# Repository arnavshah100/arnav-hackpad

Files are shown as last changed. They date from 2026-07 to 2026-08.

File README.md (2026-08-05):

# arnav-hackpad
<b>The arnav-hackpad is a mini-keyboard (or macropad) designed to act as an external number pad with some other cool capabilities, too!</b>

## Inspiration
In my essential technology class at school, two of my favorite modules were coding and 3D printing. When I joined the [Stardance summer program](https://stardance.hackclub.com/) and started looking at the recommended projects, I saw <b>hackpad</b>, and saw it as a great way to combine my love for those two subjects.
## Features
- 2 EC11 Rotary Encoders with Switches
- 10 MX-Style Key Switches
- 3-Part Case
## CAD Model
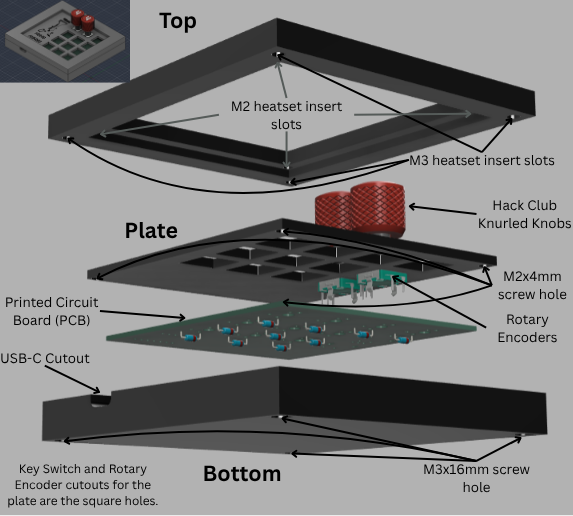
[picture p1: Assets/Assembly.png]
View Assembly on Autodesk Fusion's web version (https://a360.co/4eWbKiA)
\
This is my assembled macropad. Click on it to interact with the assembled macropad in Autodesk Fusion's web version.

There are 3 parts to the case: the top, the bottom, and the plate. The arnav-hackpad is top-mounted, meaning that the plate is attached to the top part. The design gives an ≈0.3mm printing tolerance. I added a cool design with my name on the plate, which you can see in the plate demo below!

[Click here to interact with the Plate.](https://a360.co/4g3hhWc)\
[Click here to interact with the Top part.](https://a360.co/4vbjJyh)\
[Click here to interact with the  Bottom part.](https://a360.co/4pMDXNC)
## PCB
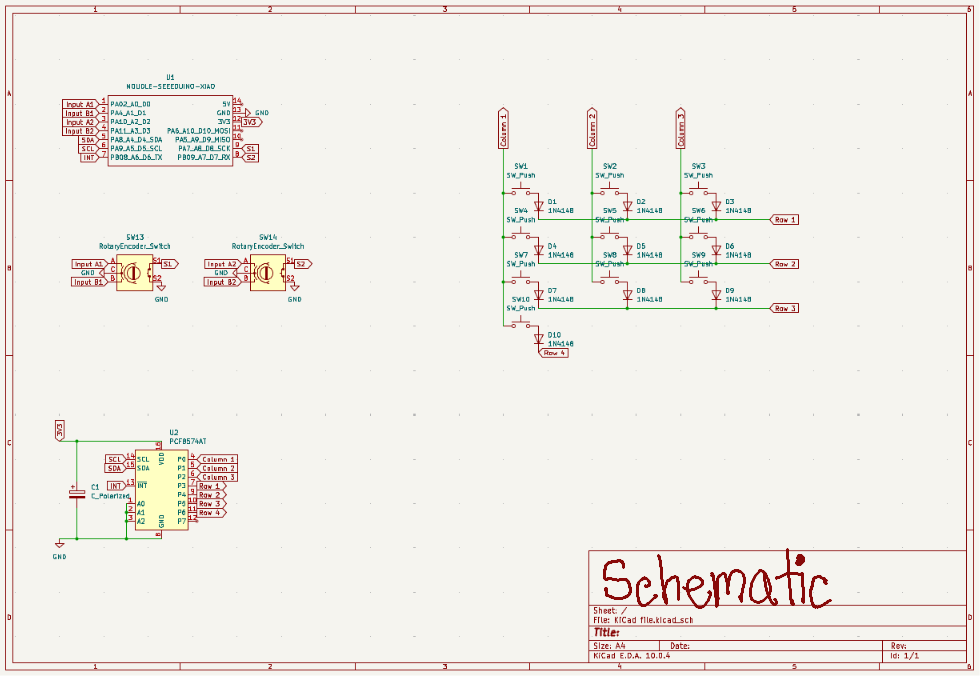
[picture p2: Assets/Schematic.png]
View Schematic on KiCanvas (https://kicanvas.org/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)


This is my PCB's schematic. Click on it to interact with the schematic in KiCanvas.

I used a PCF8574AT I/O expander because all of the pins would not fit on the microchip.

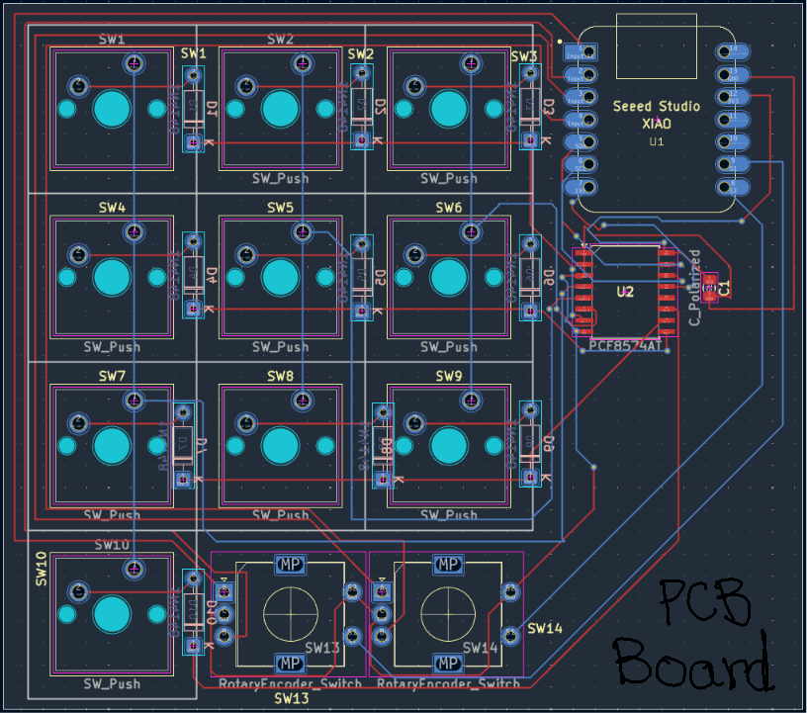
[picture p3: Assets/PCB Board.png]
View PCB on KiCanvas (https://kicanvas.org/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)


This is my PCB board. Click on it to interact with the PCB Board in KiCanvas.

I know it's very messy, but everything works out in the end!
## Firmware Overview
The macropad is coded using KMK firmware.
- The rotary encoder on the left changes volume, and its switch works as the mute key.
- The rotary encoder on the right changes brightness, and its switch works as the print screen key.
- The key switches are arranged in the same way as the numbers are in a number pad.

## How to make it
### Bill of Materials
To make this macropad, you will need the following:
- 10x Cherry MX Switches
- 10x 1N4148 DO-35 Diodes
- 10x DSA Keycaps
- 2x EC11 Rotary Encoder
- 2x Hack Club Knurled Knob (Replaceable with another knob for EC11 Rotary Encoder)
- 1x XIAO RP2040
- 1x PCF8574AT
- 1x 0805 SMD Capacitor
- 4x M3 x D5mm x L4mm Heatset Inserts
- 4x M2 x D4mm x L3mm Heatset Inserts
- 4x M3 x 16mm screws
- 4x M2 x 4mm screws
- 1x Case (3 printed parts)
- 1x USB-C cable
- 1x Soldering Iron
### PCB
Use the [Gerbers.zip file](Production/Gerbers.zip) to print the PCB from whatever company you want. Make sure you choose the <b>2-layer</b> PCB option. When you solder the components together, make sure to refer to the [online PCB image](https://kicanvas.org/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) often.
### 3D Printing
Use the [Plate.step file](Production/CAD%20files/Plate.step), [Top.step file](Production/CAD%20files/Top.step), [Bottom.step file](Production/CAD%20files/plate.step), and [Hack Club Knurled Knob.step file in case you are using it](Production/CAD%20files/Hack%20Club%20Knurled%20Knob.step). If you are printing it yourself, I suggest using google to figure out how to print on your specific 3D printer. Otherwise, just give the files above to whoever is printing it. Make sure you use either PLA, ABS, PETG, or Nylon, because certain plastics don't work with heatset inserts.
### Assembly
<b>If you do not know how to do any part of this tutorial, Google can teach you how to!</b>

Finally, it's time to do the assembly! Put the M3 x D5mm x L4mm heatset inserts on the outer holes of the top part, and put the M2 x D4mm x L3mm heatset inserts on the inner holes of the top part. You can use [this image](Assets/ScrewImage.png) to help you.

Next, put the key switches and rotary encoders into the plate. <b>MAKE SURE THE PINS ARE ALIGNED CORRECTLY WITH THE PCB!</b> Put the keycaps on the key switches.

Next, install the firmware onto the microchip. [This is a great guide to help you for this step.](https://wiki.seeedstudio.com/XIAO-RP2040-with-CircuitPython/)

Afterward, <b><i><u>carefully</u></i></b> solder the keyswitches onto the PCB.

For the last step, use the M2x4mm screws to screw the plate onto the top part's M2 heatset insert. The top part of the screw should be touching the plate. I recommend plugging in the PCB into your device and trying using the macropad to check that it works. If your device dpesn't register any of the keypresses, reread all the steps in [the guide](https://github.com/arnavshah100/arnav-hackpad/#how-to-make-it). Use the M3x16mm screws to screw the bottom part onto the top part's M3 heatset insert. The top part of the screw should be touching the bottom part. The labeled image showing where the screws should be is [here](Assets/Assembly.png).

Now, put the knob on the rotary encoder, and you're DONE! <b><u>CELEBRATE!</b></u>

## Credits
- Huge thanks to [@ashah80](https://github.com/ashah80) (my brother!), who helped me in every step of the way, even though he has never made anything hardware-related.
- I was motivated by the [Stardance summer program](https://stardance.hackclub.com/), which both inspired and incentivized me to make this project. I had never even considered making hardware (except small 3D printed toys at school) before Stardance provided me with a great platform to do so.
- The people in the [hackpad slack page](https://hackclub.enterprise.slack.com/archives/C07LESGH0B0) from Hack Club helped answer all my questions.
### Resources I used
- I used [Hack Club's KiCad care package](https://github.com/hackclub/hackpad/releases/tag/v0.1-bugfix) for some of my symbols and footprints in my PCB.
- I used [KiCad's rotary encoder footprint](https://kicad.github.io/footprints/Rotary_Encoder) for my, well, rotary encoder!
- I used [Hack Club's rotary encoder and knurled knob CAD file](https://github.com/hackclub/hackpad/tree/clean/extras/CAD%20models) in my [assembled hackpad file](CAD/arnav-hackpad.step).
- I used some of the [KMK's CircuitPython libraries](https://github.com/KMKfw/kmk_firmware), a key part of my code.

<b>Thank you for <i>reading me</i>!</b>

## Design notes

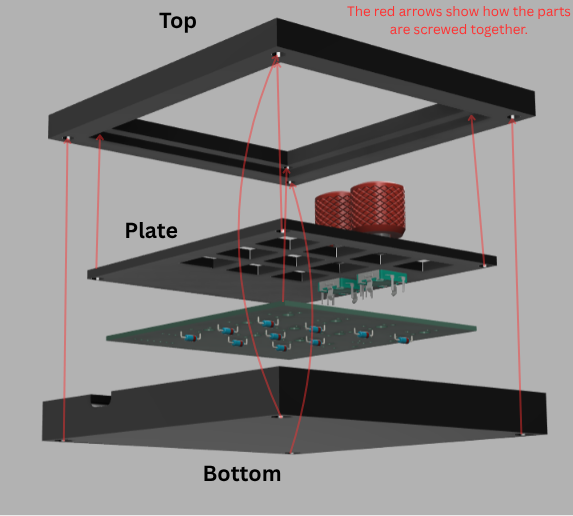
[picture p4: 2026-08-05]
Assets/ScrewImage.png

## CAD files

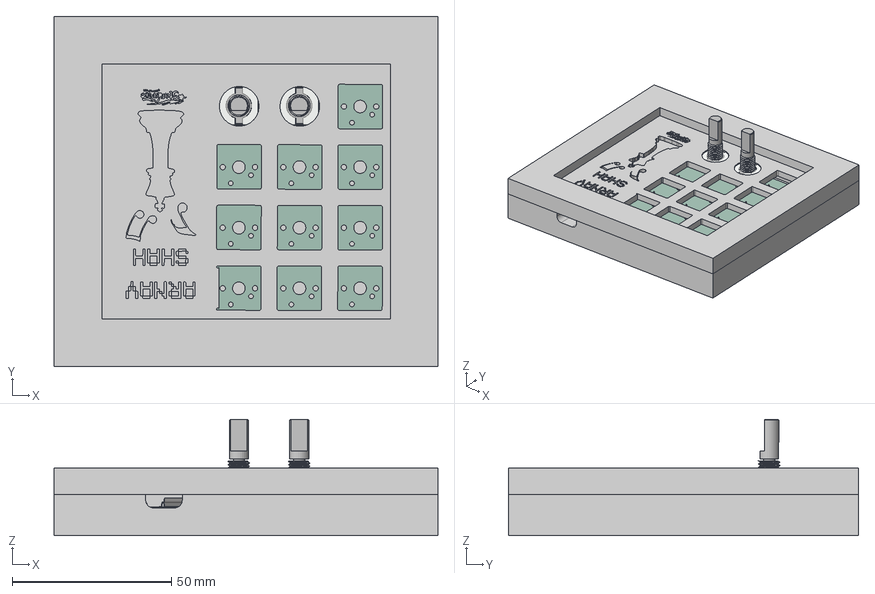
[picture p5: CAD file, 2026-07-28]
CAD/arnav-hackpad.step
120.7 x 110.2 x 36.6 mm
SOIC-16W_7.5x10.3mm_P1.27mm
C_0805_2012Metric
D_DO-35_SOD27_P7.62mm_Horizontal x 10
KiCad file_PCB
EC11E_Switch_20mm.step x 2

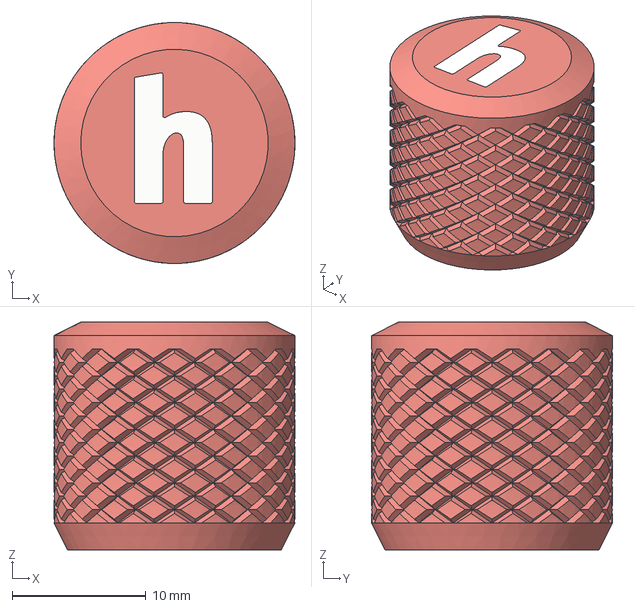
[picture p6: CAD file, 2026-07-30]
Production/CAD files/Hack Club Knurled Knob.step
18.0 x 18.0 x 17.0 mm
Base
H

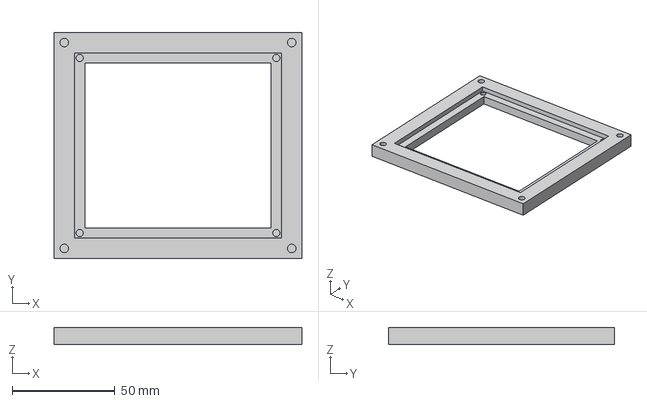
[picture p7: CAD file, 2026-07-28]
Production/CAD files/Top.step
120.7 x 110.2 x 8.34 mm

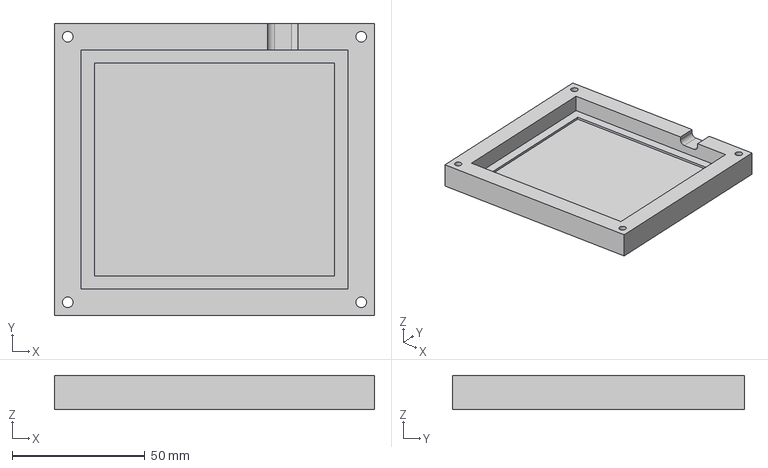
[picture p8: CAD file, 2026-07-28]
Production/CAD files/Bottom.step
120.7 x 110.2 x 13.0 mm

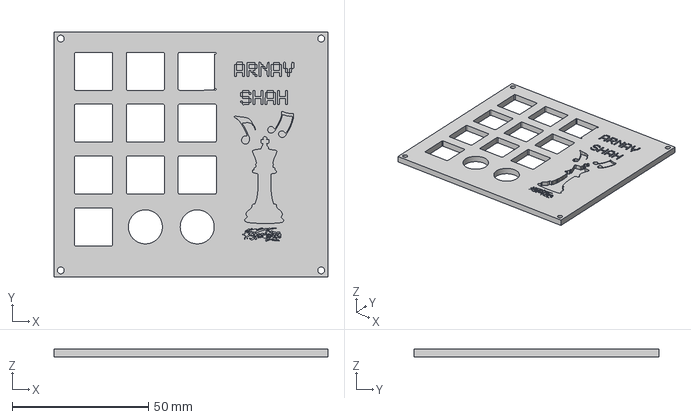
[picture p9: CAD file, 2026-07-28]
Production/CAD files/Plate.step
100.7 x 90.2 x 3.00 mm

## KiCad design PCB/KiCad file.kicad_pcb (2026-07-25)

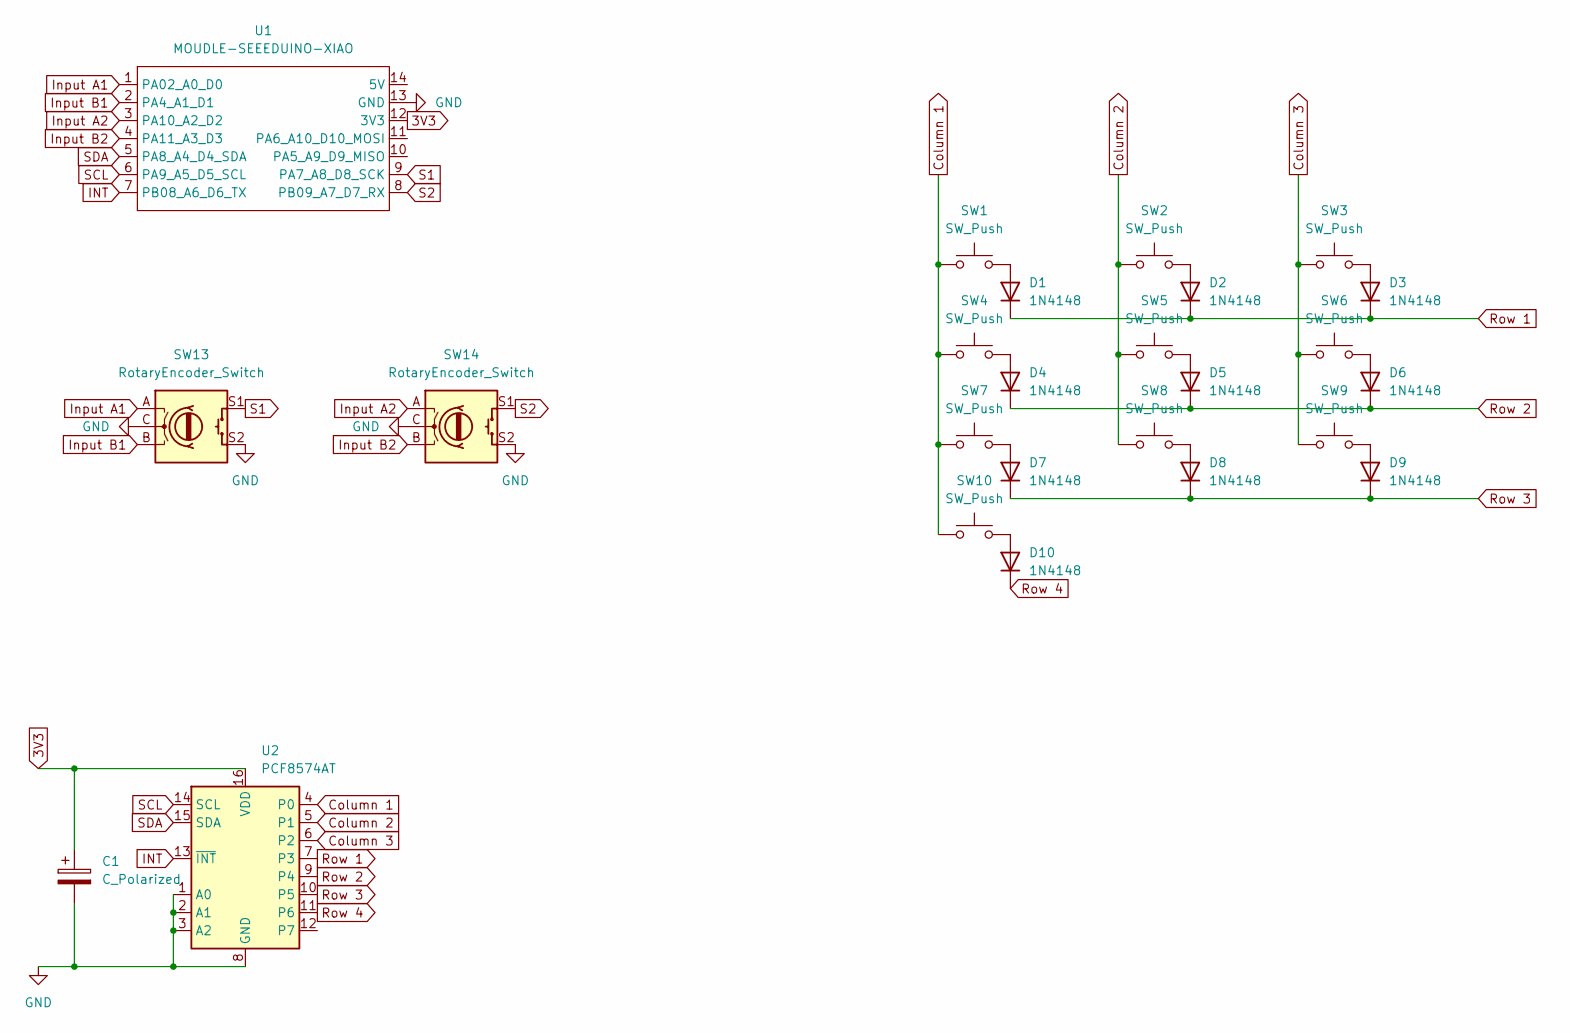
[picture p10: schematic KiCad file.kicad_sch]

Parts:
C1: C_Polarized; C_0805_2012Metric
D1, D2, D3, D4, D5, D6, D7, D8, D9, D10: 1N4148; D_DO-35_SOD27_P7.62mm_Horizontal
SW1, SW2, SW3, SW4, SW5, SW6, SW7, SW8, SW9, SW10: SW_Push; SW_Cherry_MX_1.00u_PCB
SW13, SW14: RotaryEncoder_Switch; RotaryEncoder_Alps_EC11E-Switch_Vertical_H20mm
U1: MOUDLE-SEEEDUINO-XIAO; XIAO-Generic-Hybrid-14P-2.54-21X17.8MM
U2: PCF8574AT; SOIC-16W_7.5x10.3mm_P1.27mm

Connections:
3V3: C1.1, U1.12 (3V3), U2.16 (VDD)
Column 1: SW1.1, SW4.1, SW7.1, SW10.1, U2.4 (P0)
Column 2: SW2.1, SW5.1, SW8.1, U2.5 (P1)
Column 3: SW3.1, SW6.1, SW9.1, U2.6 (P2)
GND: C1.2, SW13.C, SW13.S2, SW14.C, SW14.S2, U1.13 (GND), U2.1 (A0), U2.2 (A1), U2.3 (A2), U2.8 (GND)
INT: U1.7 (PB08_A6_D6_TX), U2.13 (~INT)
Input A1: SW13.A, U1.1 (PA02_A0_D0)
Input A2: SW14.A, U1.3 (PA10_A2_D2)
Input B1: SW13.B, U1.2 (PA4_A1_D1)
Input B2: SW14.B, U1.4 (PA11_A3_D3)
unnamed: D1.2 (A), SW1.2
unnamed: D2.2 (A), SW2.2
unnamed: D3.2 (A), SW3.2
unnamed: D4.2 (A), SW4.2
unnamed: D5.2 (A), SW5.2
unnamed: D6.2 (A), SW6.2
unnamed: D7.2 (A), SW7.2
unnamed: D8.2 (A), SW8.2
unnamed: D9.2 (A), SW9.2
unnamed: D10.2 (A), SW10.2
Row 1: D1.1 (K), D2.1 (K), D3.1 (K), U2.7 (P3)
Row 2: D4.1 (K), D5.1 (K), D6.1 (K), U2.9 (P4)
Row 3: D7.1 (K), D8.1 (K), D9.1 (K), U2.10 (P5)
Row 4: D10.1 (K), U2.11 (P6)
S1: SW13.S1, U1.9 (PA7_A8_D8_SCK)
S2: SW14.S1, U1.8 (PB09_A7_D7_RX)
SCL: U1.6 (PA9_A5_D5_SCL), U2.14 (SCL)
SDA: U1.5 (PA8_A4_D4_SDA), U2.15 (SDA)

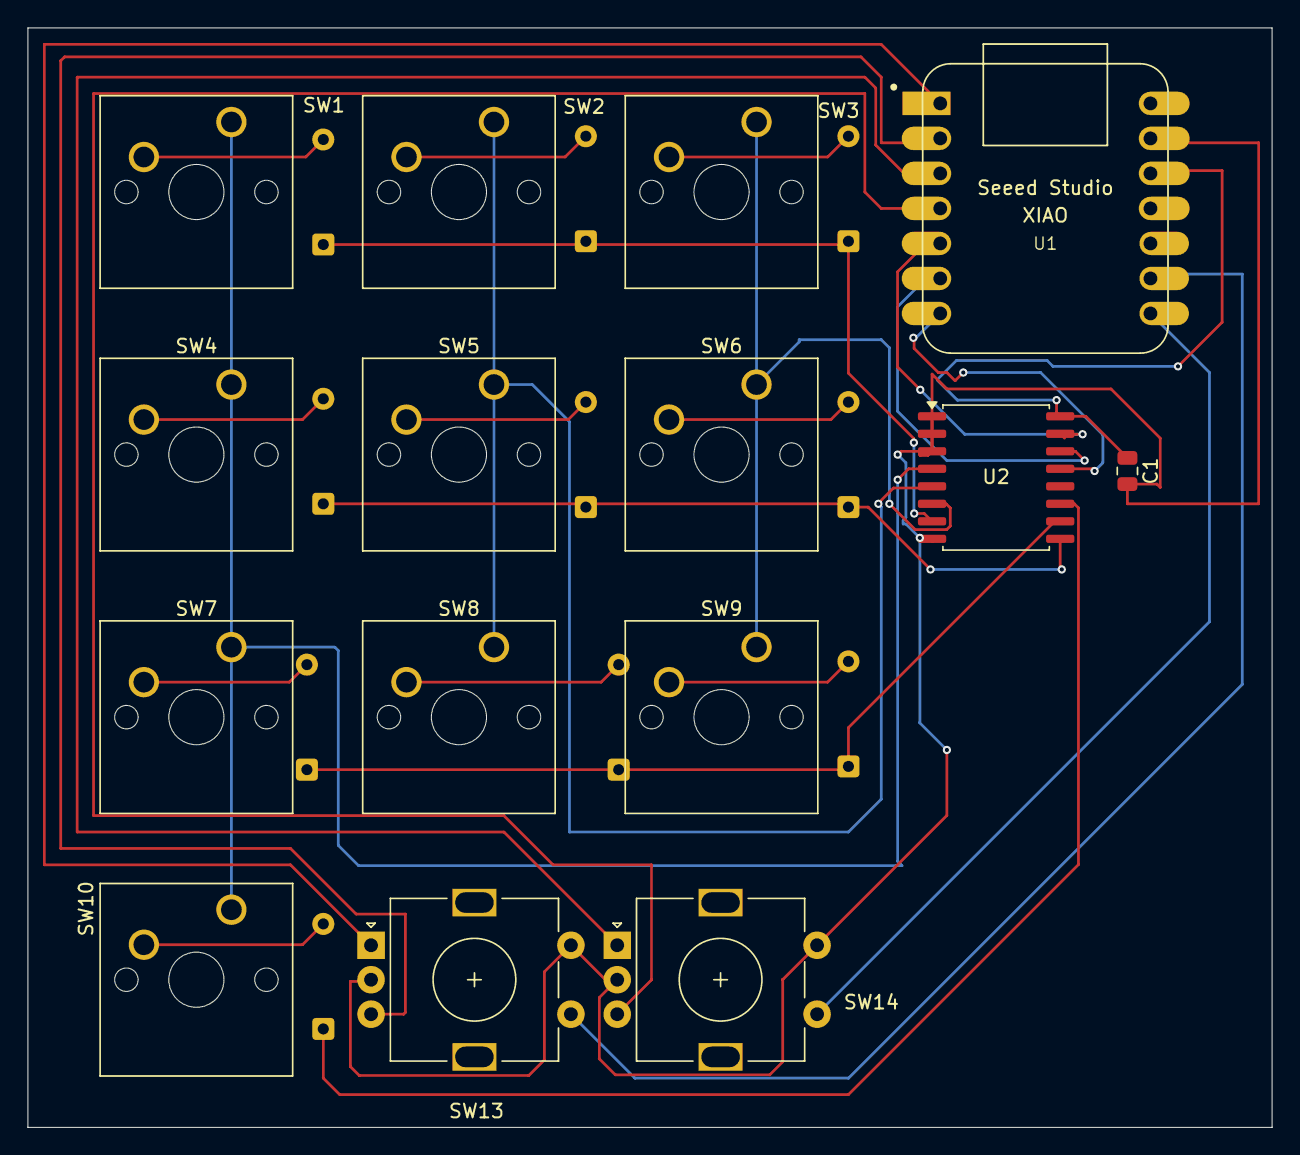
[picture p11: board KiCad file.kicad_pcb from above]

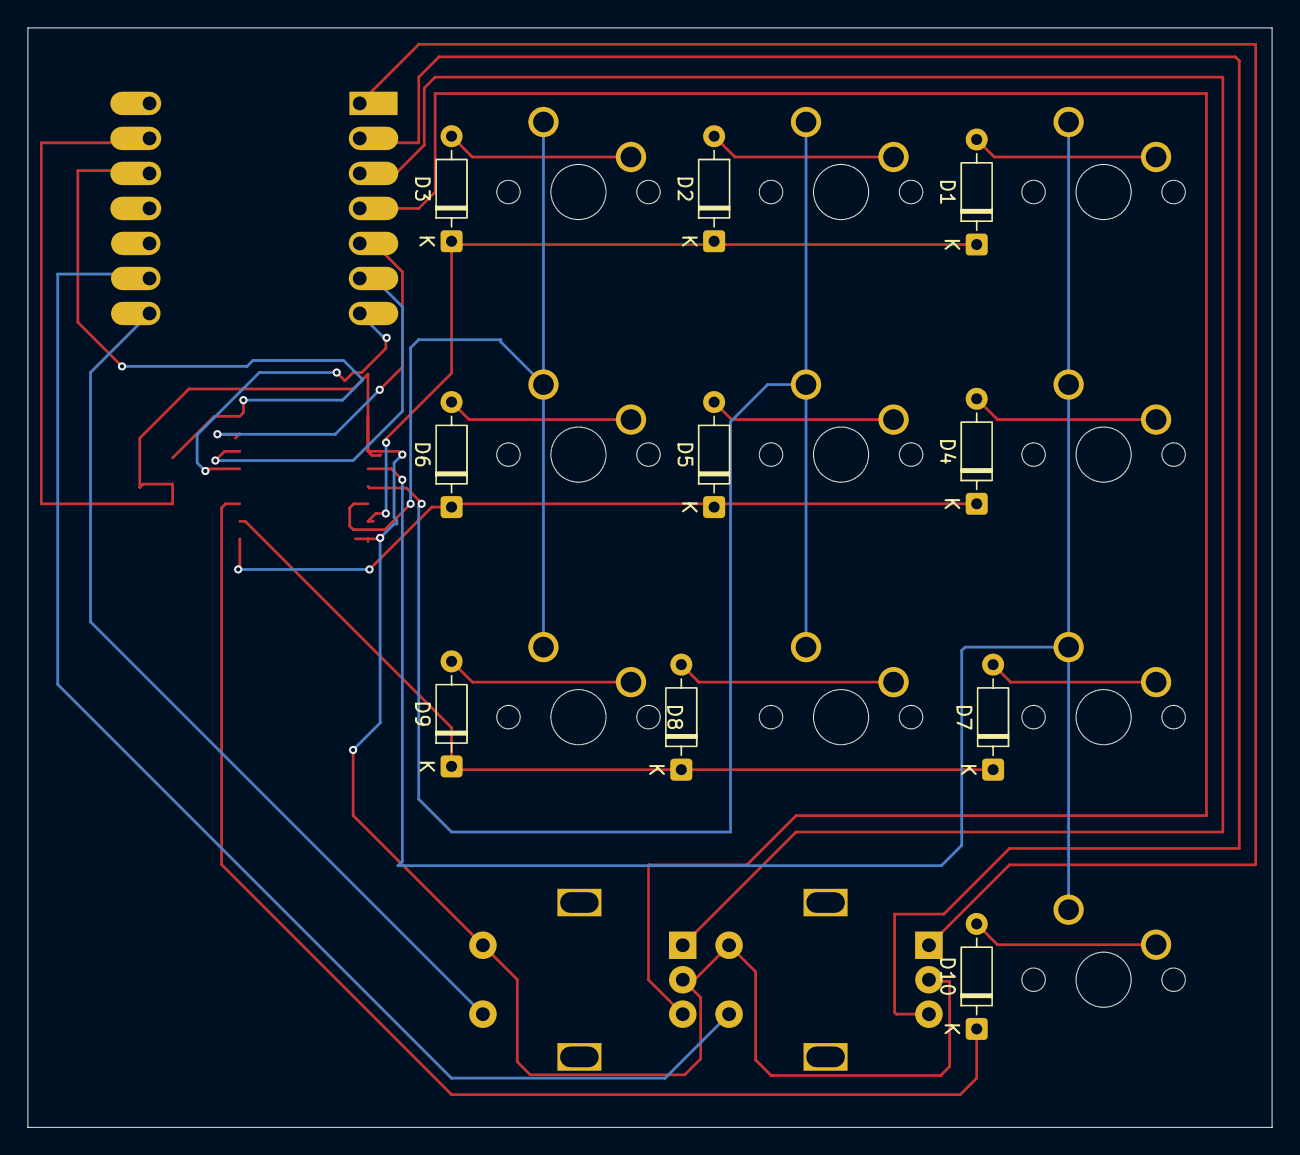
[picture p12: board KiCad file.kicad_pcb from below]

Board: 2 copper layers, 90.3 x 79.8 mm, 25 parts (10 on the bottom side), 28 nets.

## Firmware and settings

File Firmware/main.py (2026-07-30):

# Prerequisites
import board
import busio
import digitalio
 
from kmk.kmk_keyboard import KMKKeyboard
from kmk.keys import KC
from kmk.scanners import DiodeOrientation
from kmk.scanners.digitalio import MatrixScanner
from kmk.scanners.keypad import KeysScanner
from kmk.scanners.encoder import RotaryioEncoder
 
import adafruit_pcf8574

keyboard = KMKKeyboard()
#------------------------
# I2C Configuration
# what am i supposed to write for frequency?
i2c = busio.I2C(scl=board.D5, sda=board.D4, frequency=100_000)
pcf = adafruit_pcf8574.PCF8574(i2c, address=0x38)
#------------------------
# Matrix
colpins = [pcf.get_pin(0), pcf.get_pin(1), pcf.get_pin(2)]
rowpins = [pcf.get_pin(3), pcf.get_pin(4), pcf.get_pin(5), pcf.get_pin(6)]

matrix = MatrixScanner(
    cols=colpins,
    rows=rowpins,
    diode_orientation=DiodeOrientation.ROW2COL,
    #The PCF8574AT has active-low scanning, and that switches the orientation from how the diodes are wired in the PCB.
    pull=digitalio.Pull.UP,
)
#------------------------
# Rotary Encoders with Switches
encoder_switches = KeysScanner(
    pins = [board.D8, board.D7],
    value_when_pressed = False,
    pull = True,
)
encoder_1 = RotaryioEncoder(pin_a=board.D0, pin_b=board.D1, divisor=4)
encoder_2 = RotaryioEncoder(pin_a=board.D2, pin_b=board.D3, divisor=4)
#------------------------
# Coding the matrix
keyboard.matrix = [matrix, encoder_switches, encoder_1, encoder_2]
keyboard.keymap = [
    [
    KC.N7, KC.N8, KC.N9,
    KC.N4, KC.N5, KC.N6,
    KC.N1, KC.N2, KC.N3,
    KC.N0, KC.NO, KC.NO,

    KC.MUTE, KC.PSCR,
    KC.VOLD, KC.VOLU,
    KC.BRID, KC.BRIU,
    ]
]
#------------------------
# Final Lines
if __name__ == '__main__':
    keyboard.go()

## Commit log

2026-07-21 Added KiCad files
    [KiCad file.kicad_pcb, KiCad file.kicad_sch]
2026-07-25 Finished PCB files
    I completely finished my PCB and created the gerbers for exporting!
    [KiCad file.kicad_pcb, KiCad file.kicad_sch]
2026-07-28 Added CAD files
    I finished creating all the CAD files for the hackpad.
    [Bottom.step, Plate.step, Top.step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]
2026-07-30 Added many changes, most minor but some major.
    I created my readme and added an assets folder to load screenshots into the readme. Also, I added PCB libraries so others can make their own version of the PCB.
    [Hack Club Knurled Knob.step, KiCad file.kicad_sch]
2026-10-18 Made the hackpad and changed everything so it is better. Added pull up resistors and madee code actually work
